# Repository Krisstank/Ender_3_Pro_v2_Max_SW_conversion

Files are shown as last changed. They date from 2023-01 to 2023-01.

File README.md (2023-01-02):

# Ender 3 Pro/V2 to Switchwire Conversion

This is a full conversion of the popular Ender 3 Pro/V2 to a Voron Switchwire and a collaborate work with [Triano](https://github.com/walttriano). The motivation came from [his awesome original conversion](https://github.com/walttriano/VoronUsers/tree/master/printer_mods/Triano/Ender_3Pro_Switchwire) that was used as a starting point, however almost everything was re-designed from scratch (in order to follow the Voron guidelines and aesthetics more accurately). Another factor that led to this re-design, was the need to be able to enclose this printer in a, visually, pleasant and, structurally, functional way. The ingenious design of 5x MGN12H Linear Rails - 300mm (dual Y axis rail) from Triano was preserved and the printing volume is ~220x220x220.

(For assembly tips regarding some unique parts of this conversion, check the [Wiki](https://github.com/boubounokefalos/Ender_SW/wiki)).

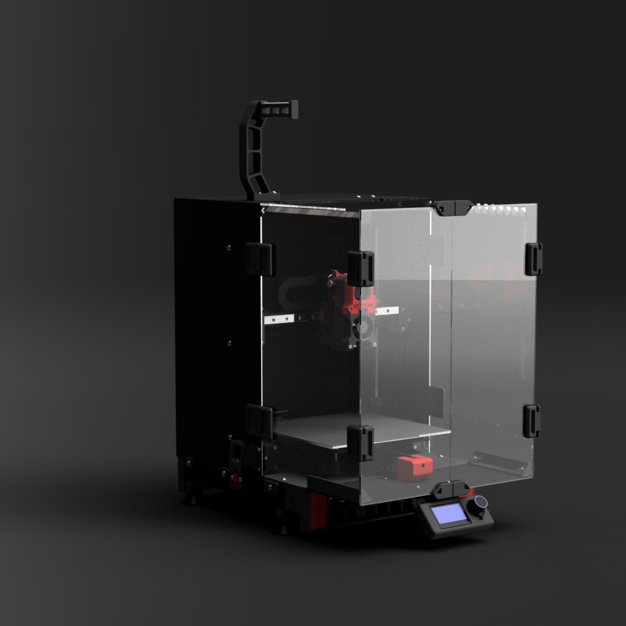
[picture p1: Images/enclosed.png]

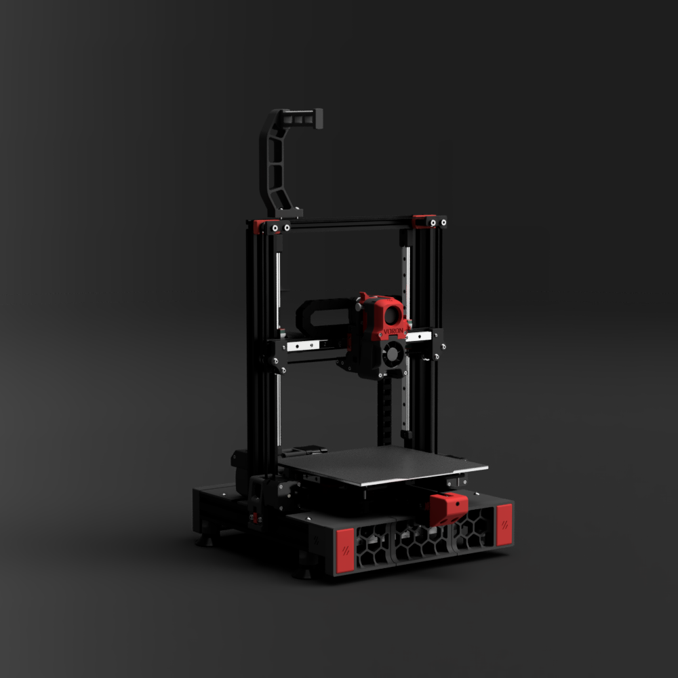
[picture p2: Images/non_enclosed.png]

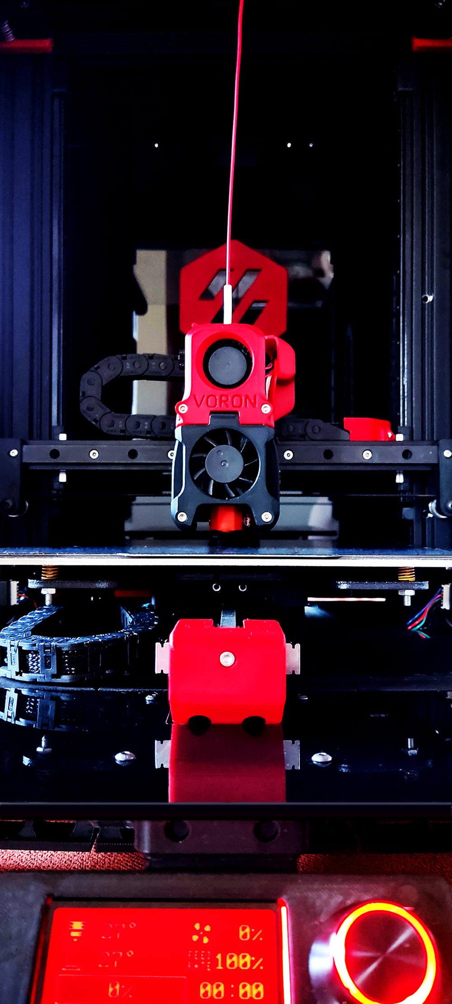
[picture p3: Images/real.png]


## Info

Various parts _can*_ be recycled from the Ender 3 Pro/V2, most important ones are:
- The frame (though a 310mm extrusion is needed for the X. You can chop the original one to length).
- The MeanWell PSU.
- The heatbed assemble.
- The original board.
- XYZ motors (as long as you can pull off the pulleys. An aftermarket 20mm motor is needed for the printhead extruder though).
- All the cables that don't go through the cable-chains (for there, silicone or PTFE cable is adviced).
- 4010 fan for the tool cooling.

*cheaping out in parts can lead into several problems, such as poor printing quality or, even worse, safety hazard. Keep that in mind and use parts from the official Switchwire BOM.

## Files

- Most of the printed part files needed for this conversion, are included in this git (you will only need to get the Afterburner print files from the [official Switchwire git](https://github.com/VoronDesign/Voron-Switchwire/tree/master/STL/Gantry/XZ_Axis/X_Carriage) ).
- CAD files (.f3d and .STEP) are provided, in order to help the building process, but they also serve as a BOM (in case you need to find proper screw lengths etc).
- DXF files in order to cut your enclosure panels.
- A printer.cfg as a starting point (based off LDO motors and SKR E3 mini V2 board).

## Credits

- Ofc to Triano for his awesome design and all the valuable help, info and support.
- To marcel#0874 for his original idea of the sticky grill endcaps.
- To sdukan#9213 for his valuable help into troubleshooting the Ender 3 V2 differences, electronics (and in general)
- To all of this awesome community of people.
- To Voron design team for all the valuable resources and the solid base.

## Disclaimer

This is a very carefuly designed build.. however mistakes could have been made so by deciding to follow this conversion, you are responsible for any possible damage done to the printer or even yourself. This is serious so keep that in mind.

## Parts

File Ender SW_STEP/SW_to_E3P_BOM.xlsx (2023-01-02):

Category | Component | Standard | Qty | Required for the Ender 3 Pro Mod?
Filament | Primary Color (Black) |  | 1 | Yes
Filament | Secondary Color (Red) |  | 1 | Yes
Printed Parts | Printed Parts |  | 1 | Yes - STLs on GitHub
Fasteners | M8x16 BHCS | ISO 7380 | 8 | M3 and M5 assorted fasteners are required. I didn't detail out the various lengths
Fasteners | M5x40 SHCS | ISO 4762 / DIN 912 | 6
Fasteners | M5x30 BHCS |  | 5
Fasteners | M5x16 BHCS | ISO 7380-1 | 12
Fasteners | M5x10 BHCS | ISO 7380-1 | 50
Fasteners | M4x8 BHCS | ISO 7380-1 | 4
Fasteners | M3x40 SHCS | ISO 4762 / DIN 912 | 7
Fasteners | M3x30 SHCS | ISO 4762 / DIN 912 | 28
Fasteners | M3x25 SHCS | ISO 4762 / DIN 912 | 2
Fasteners | M3x20 SHCS | ISO 4762 / DIN 912 | 3
Fasteners | M3x16 SHCS | ISO 4762 / DIN 912 | 12
Fasteners | M3x12 SHCS | ISO 4762 / DIN 912 | 12
Fasteners | M3x8 SHCS | ISO 4762 / DIN 912 | 66
Fasteners | M3x6 BHCS | ISO 7380-1 | 6
Fasteners | M3x6 FHCS | ISO 10642 | 16
Fasteners | M3x12 FHCS | ISO 10642 | 9
Fasteners | 6x6x3 Spacer
Fasteners | M2x10 Self Tapping Screw for Plastics |  | 8
Fasteners | M3 Threaded Insert |  | 54
Fasteners | 5x10x1 Shim Ring | DIN 988 | 19
Fasteners | M3 Hexnut | ISO 4033 / DIN 934 | 3
Fasteners | M3 T-nut (For 2020 extrusions) |  | 13
Fasteners | M3 T-nut (For 3030 extrusions) |  | 12
Fasteners | M5 T-nut (For 2020 extrusions) |  | 12
Fasteners | M5 T-nut (For 3030 extrusions) |  | 52
Motion | GT2 Open Belt LL-2GT-6 (6mm wide) - 1500mm |  | 2 | Yes
Motion | GT2 Open Belt LL-2GT-6 (6mm wide) - 800mm |  | 1 | Yes
Motion | GT2 20T (6mm wide) Pulley (5mm bore) |  | 3 | Yes
Motion | F695 2RS Bearing |  | 20 | Yes
Motion | Linear Rail MGN12H (300mm) |  | 4 | 5 (1 additional)
Motion | Key-bak Super48 13oz |  | 1 | Yes
Vibration Management | Rubber Compressor Foot |  | 4 | No - printed with the forward and aft grills
Electronics | Omron Mouse Button - Micro Switch |  | 2 | 1 - the Y axis microswitch is reused
Electronics | Omron TL-Q5MC2 - NPN, NC, 5mm Sense |  | 1 | Yes
Electronics | BAT85 Diode |  | 1 | Yes
Electronics | NEMA17 Motor 17HS15-1504S1 |  | 3 | New or Reused. If you have a gear puller, you can reuse these. I bought new ones. You also need the smaller motor for the afterburner.
Electronics | Mean Well LRS-350-24 PSU |  | 1 | Reused
Electronics | Mean Well RS-25-5 PSU |  | 1 | Yes
Electronics | ZF - Rocker Switches DPST 16A ON-OFF |  | 1 | No
Electronics | Fuse Medium Time Delay Acting 8A 250V Holder Cartridge 5 X 20mm Glass |  | 2 | Yes
Electronics | TycoElectronics - 10EGG1-2 (Normal) or 10EHG1-2 (Medical): Filtered Power Inlet |  | 1 | No
Electronics | IEC320 C14 Inlet - Push-fit - w/ Rocker Switch & Fuse |  | 1 | Yes
Electronics | 40x40x10 Axial Fan- Ball Bearing (24V) |  | 1 | Yes
Electronics | 40x40x20 Centrifugal Blower Fan - Ball Bearing (24V) |  | 1 | Yes
Electronics | 60x60x20 Axial Fan (24V) |  | 1 | Yes
Controller | RaspberryPi4 |  | 1 | Reused ( I was running Octoprint)
Controller | MicroSD Card |  | 1 | Reused
Controller | USB C Power Cable |  | 1 | Reused
Controller | SKR Mini E3 V2 |  | 1 | Reused or new. I had upgraded before the mod
Controller | USB Cable A-male Mini B-male (Included with SKR Mini) |  | 1 | A right angle USB mini is required
Controller | Mini 12864 Display (Type B) |  | 1 | Optional. I don't use one
Frame | Misumi 3060 x 520mm - HFSB6-3060-520-AH105-BH415-AV180 |  | 2 | Use Ender 3 Pro frame
Frame | Misumi 3030 x 400mm - HFSB6-3030-400-TPW |  | 2 | Use Ender 3 Pro frame
Frame | Misumi 3030 x 360mm - HFSB6-3030-360-LCH-RCH |  | 1 | Use Ender 3 Pro frame
Frame | Misumi 3030 x 300mm - HFSB6-3030-300-TPW |  | 2 | Use Ender 3 Pro frame
Frame | Misumi 2020 x 340mm - HFSB5-2020-340-AH15-BH325 |  | 1 | Use Ender 3 Pro frame
Frame | Misumi 2020 x 340mm - HFSB5-2020-340 |  | 1 | Use Ender 3 Pro frame
Misc | Bowden Tube (4mm OD, 3mm ID) |  | 3m | Reused
Misc | 6mm x 3mm Round Neodymium Magnets |  | 8 | No
Cables | Fork Spade Terminal |  | 15 | I have a various assorment of connectors as Voron recommends. The quantities may be off and everyone has their own preferences for wiring Yes
Cables | Insulated Crimp Receptical |  | 10 | Yes
Cables | Nylon Cable Ties 4" |  | 100 | Yes
Cables | MicroFit3 Male Pin (43031-0007) |  | 40 | Yes
Cables | MicroFit3 Female Pin (43030-0007) |  | 40 | Yes
Cables | MicroFit Connector Receptacle 4 Position (43645-0400) |  | 4 | Yes
Cables | MicroFit Connector Receptacle 3 Position (43645-0300) |  | 1 | Yes
Cables | MicroFit Connector Receptacle 2 Position (43645-0200) |  | 6 | Yes
Cables | MicroFit Connector Plug 4 Position (43640-0401) |  | 4 | Yes
Cables | MicroFit Connector Plug 3 Position (43640-0301) |  | 1 | Yes
Cables | MicroFit Connector Plug 2 Position (43640-0201) |  | 6 | Yes
Cables | JST-XH Female Pin |  | 40 | Yes
Cables | JST-XH Connector Plug 4 Position |  | 4 | Yes
Cables | JST-XH Connector Plug 3 Position |  | 4 | Yes
Cables | JST-XH Connector Plug 2 Position |  | 4 | Yes
Cables | 24AWG Silicone Cable (100ft total) |  | 1 | Yes
Cables | 16AWG Silicone Cable (10ft total) |  | 1 | Yes
Cables | 20AWG Silicone Cable (10ft total) |  | 1 | Yes
Cables | 10x11 Cable Chain - Openable (1m) |  | 2 | Yes
Panels | Opaque Enclosure Panels |  | 6 | No (https://www.michaels.com/corrugated-board-by-creatology/M10567770.html)
Panels | Side/Front/Top Acrylic Panels |  | 5 | No (https://www.tapplastics.com/product/plastics/cut_to_size_plastic/acrylic_sheets_clear/508)
Buildplate | Prusa MK52 Heated Bed - 24V |  | 1 | Reused Ender 3 bed
Buildplate | Spring Steel Sheet for Prusa MK52 Bed (included with TL Heated Bed) |  | 1
Buildplate | Prusa MK3 Y Carrier |  | 1
Afterburner |  |  |  | The Afterburner is unchanged. Check the BOM and sourcing guide

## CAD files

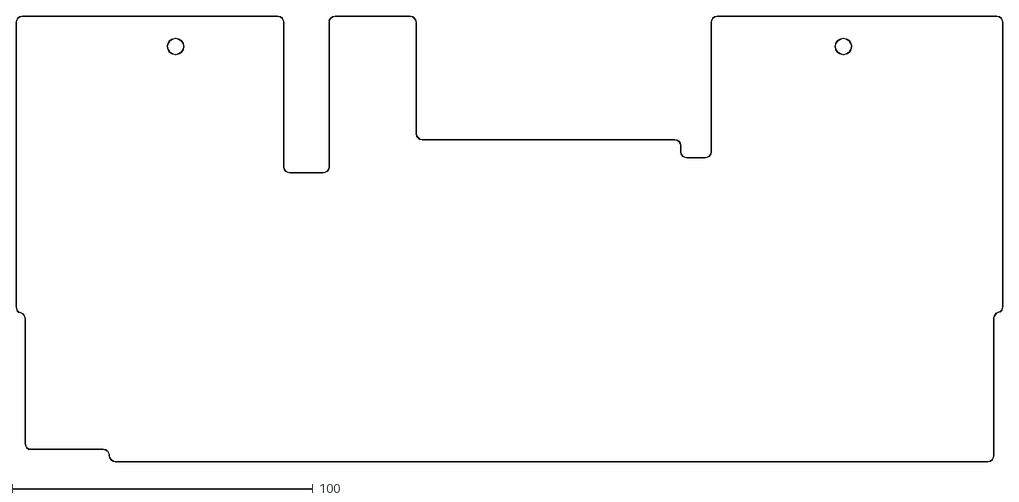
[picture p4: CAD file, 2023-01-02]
DXF/BLACK/deck_left.dxf
328.0 x 148.0

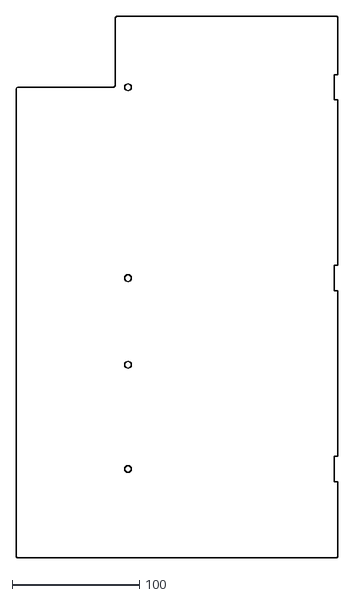
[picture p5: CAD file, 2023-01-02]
DXF/BLACK/M4_compatible/rear_side_panel_x2_M4_compatible.dxf
253.0 x 426.0

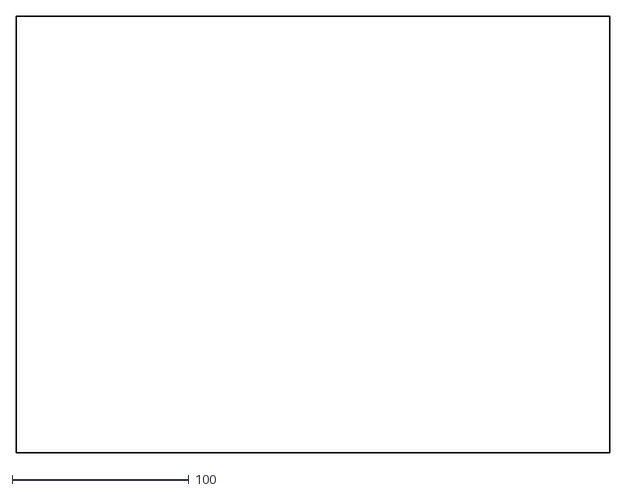
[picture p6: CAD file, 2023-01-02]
DXF/CLEAR/front_top_clear.dxf
336.0 x 247.0

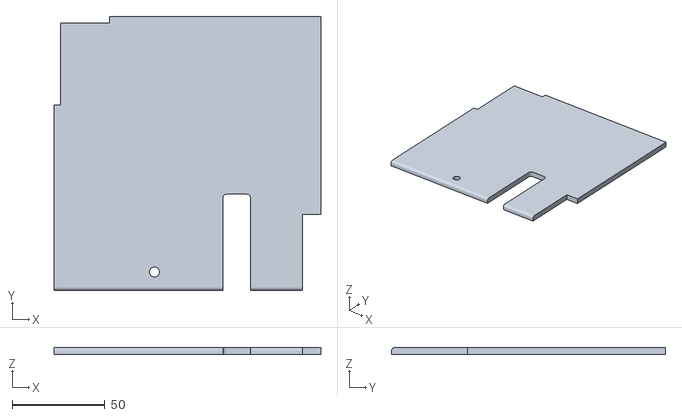
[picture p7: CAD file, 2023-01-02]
STL/Decks/rear_left.stl
144.0 x 148.0 x 4.00

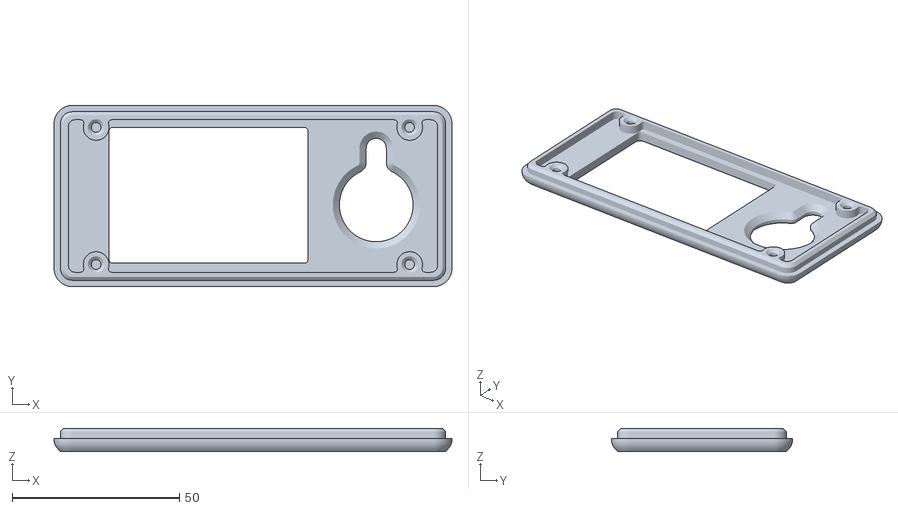
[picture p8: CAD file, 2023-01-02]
STL/Electronics/LCD/Mini12864/lcd_case_front_mini12864.stl
119.0 x 54.2 x 7.00

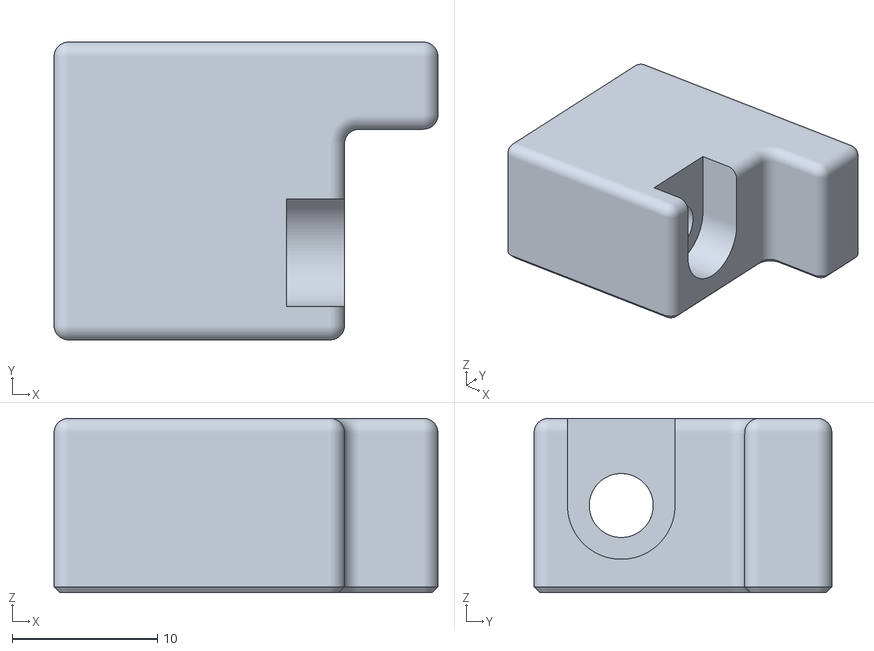
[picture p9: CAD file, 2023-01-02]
STL/Electronics/PS_4040_slide_mount_x2.stl
26.4 x 20.5 x 12.0

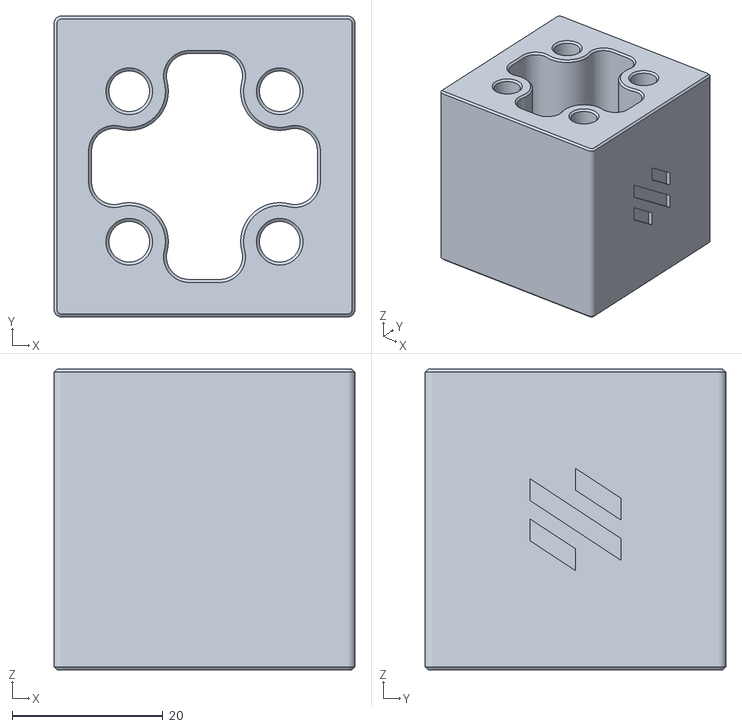
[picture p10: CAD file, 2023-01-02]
STL/frame_extension_x2.stl
40.0 x 40.0 x 40.0

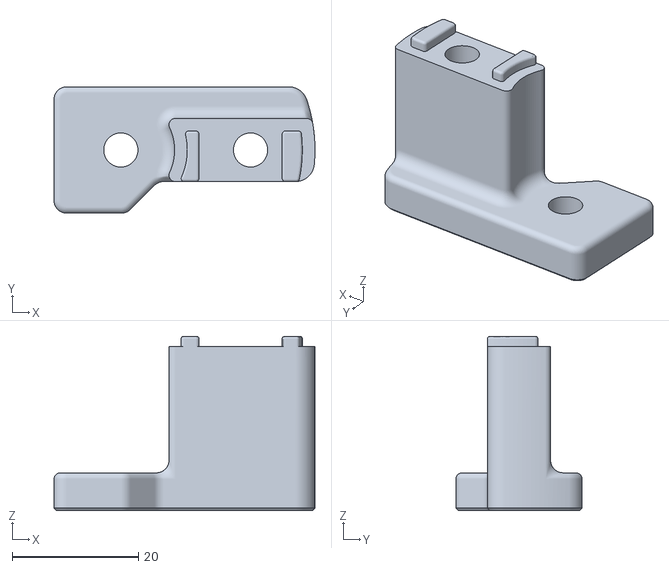
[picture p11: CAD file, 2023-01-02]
STL/Gantry/XZ_Axis/upper_idler_support_a_right.stl
41.3 x 20.0 x 27.6

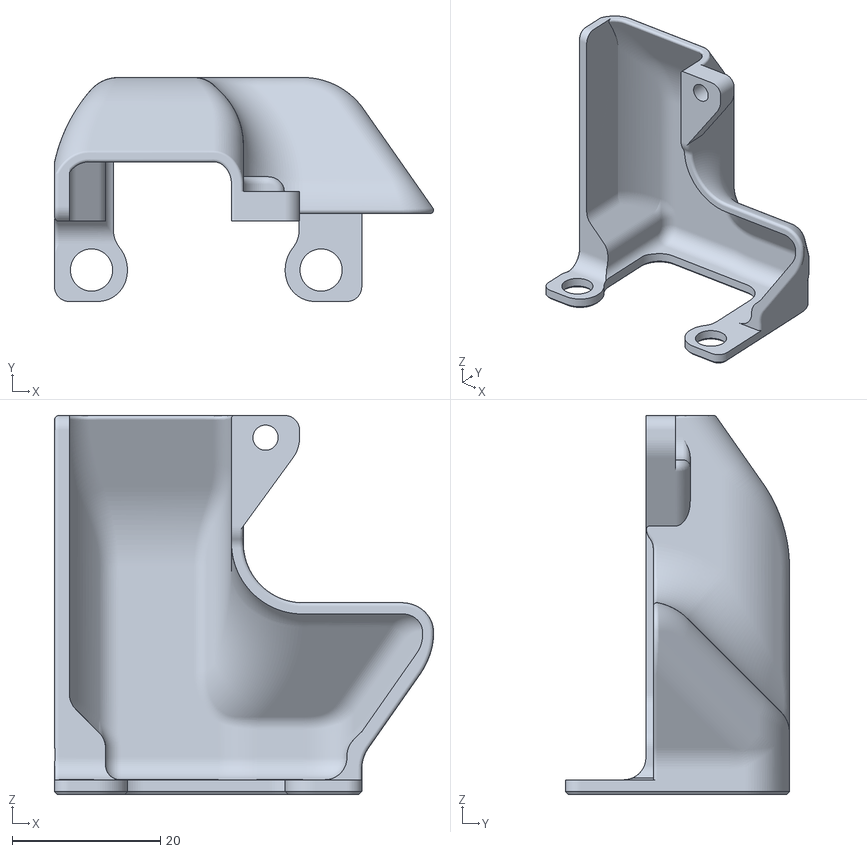
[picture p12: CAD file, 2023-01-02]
STL/Gantry/XZ_Axis/X_Axis/[a]_connector_cover.stl
51.2 x 30.3 x 51.2

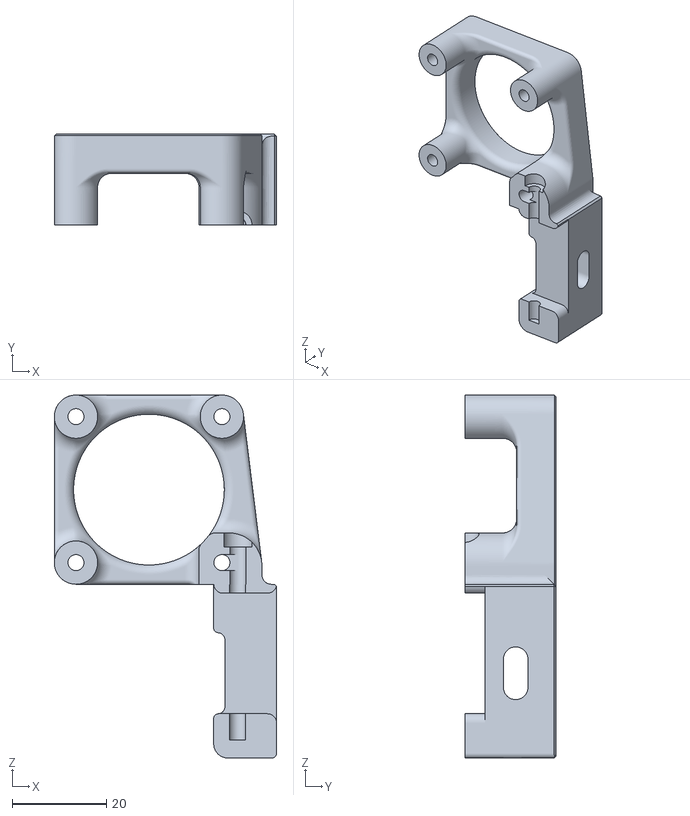
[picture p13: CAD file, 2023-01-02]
STL/Gantry/XZ_Axis/XZ_Axis_Max/x_motor_mount_b_max.stl
47.2 x 19.4 x 77.1

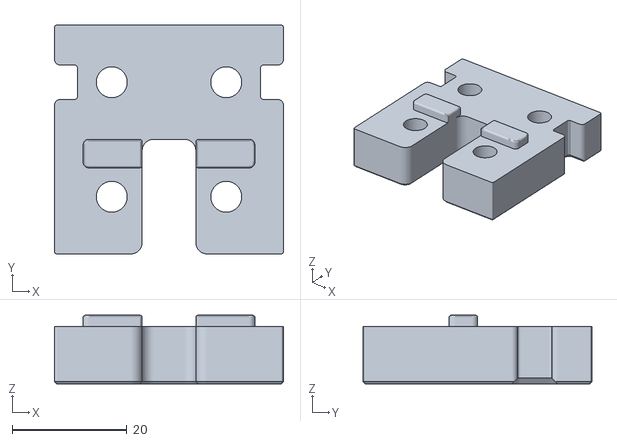
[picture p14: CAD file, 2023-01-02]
STL/Gantry/Y_Axis/y_motor_mount_bracket_enderV2.stl
40.0 x 40.0 x 12.0

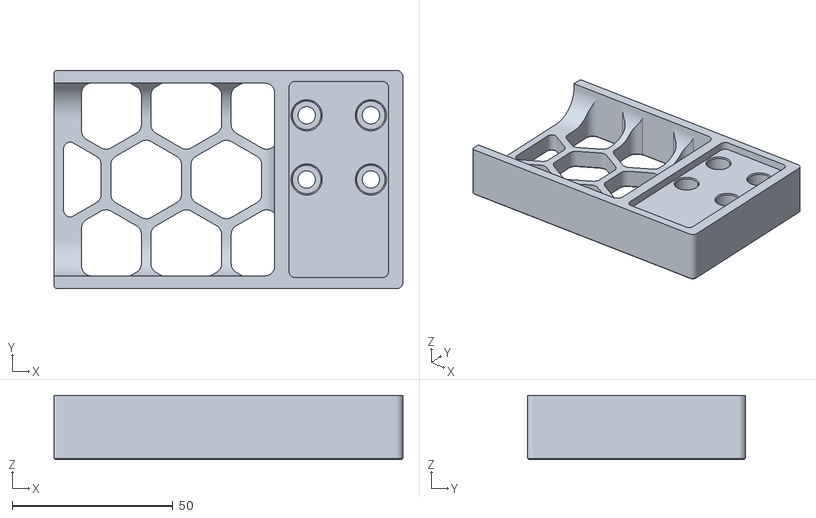
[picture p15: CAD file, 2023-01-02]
STL/Grills/grill_front_right.stl
108.7 x 68.0 x 20.0

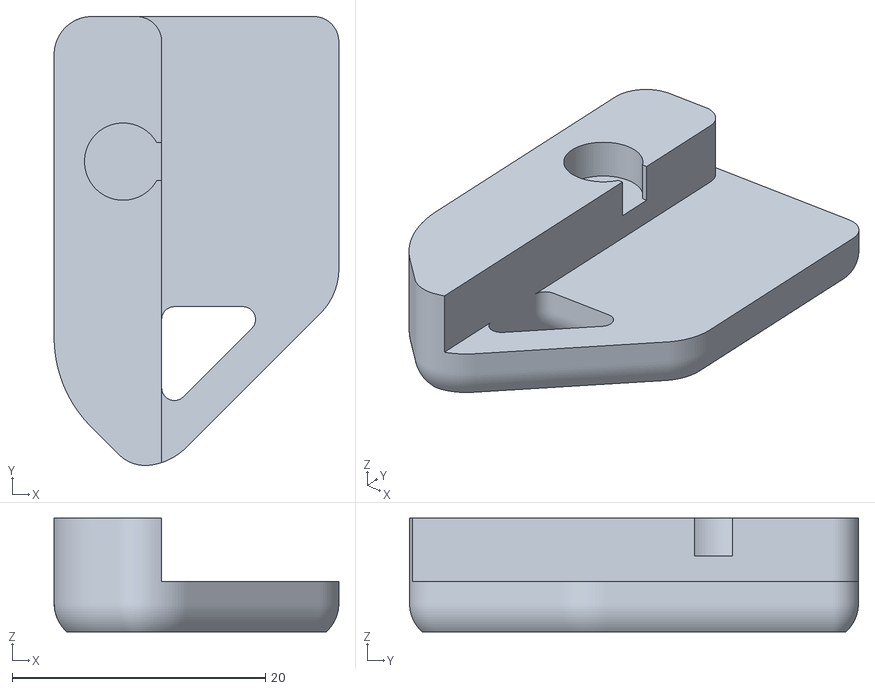
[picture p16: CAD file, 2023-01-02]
STL/Panel_Mounting/Doors/door_handle_b_x2.stl
22.5 x 35.5 x 9.00

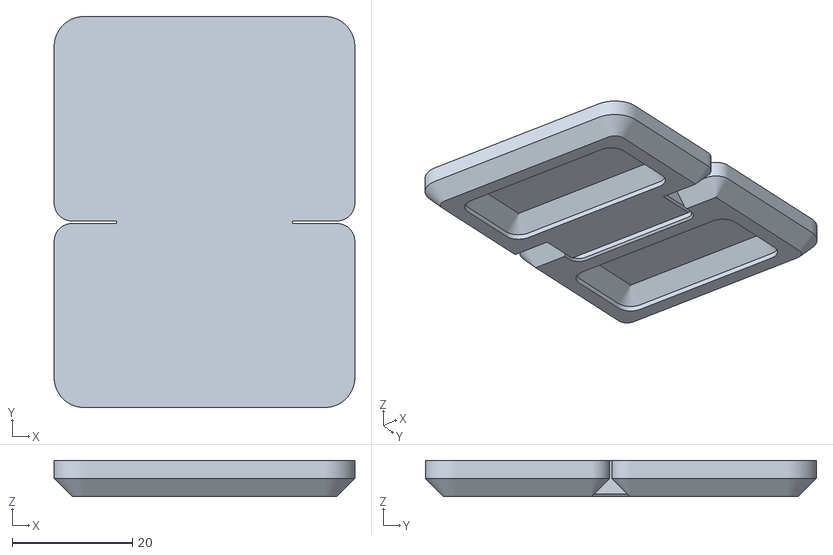
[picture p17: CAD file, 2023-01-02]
STL/Panel_Mounting/side_strap_x4.stl
50.0 x 65.0 x 6.00

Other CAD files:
DXF/BLACK/top_rear_panel.dxf
DXF/CLEAR/front_side_clear_x2.dxf
STL/Decks/rear_right.stl
STL/Electronics/LCD/Mini12864/mount_mini12864.stl
DXF/BLACK/deck_right.dxf
DXF/BLACK/front_bottom_panel.dxf
DXF/BLACK/rear_panel.dxf
DXF/BLACK/rear_side_panel_x2.dxf
DXF/CLEAR/front_clear_door_x2.dxf
STL/Decks/front_left.stl
STL/Decks/front_right.stl
STL/Electronics/LCD/Mini12864/lcd_case_rear_mini12864.stl
STL/Electronics/PS_4040_mount_a.stl
STL/Electronics/PS_4040_mount_b.stl
STL/Electronics/rpi3_mount.stl
STL/Electronics/rpi3_shelf.stl
STL/Electronics/rs_25_mount.stl
STL/Electronics/skr_mini_e3_mount.stl
STL/Gantry/XZ_Axis/XZ_Axis_Max/x_motor_mount_a_max.stl
STL/Gantry/XZ_Axis/XZ_Axis_Max/z_motor_mount_a_max.stl
STL/Gantry/XZ_Axis/XZ_Axis_Max/z_motor_mount_b_max.stl
STL/Gantry/XZ_Axis/[a]_upper_idler_support_b_left.3mf
STL/Gantry/XZ_Axis/[a]_upper_idler_support_b_left.stl
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

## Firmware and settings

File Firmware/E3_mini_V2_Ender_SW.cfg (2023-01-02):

#This is an example configuration file, for the Ender Switchwire Conversion with the SKR E3 mini V2.

[virtual_sdcard]
path: ~/gcode_files

[stepper_x]
step_pin: PB13
dir_pin: PB12
enable_pin: !PB14
rotation_distance: 40
microsteps: 16
endstop_pin: ^PC0
position_endstop: 220
position_min: 0
position_max: 220
homing_speed: 40
homing_positive_dir: true

[tmc2209 stepper_x]
uart_pin: PC11
tx_pin: PC10
uart_address: 0
run_current: 0.5
hold_current: 0.3
interpolate: True
stealthchop_threshold: 250

[stepper_y]
step_pin: PB10
dir_pin: PB2
enable_pin: !PB11
rotation_distance: 40
microsteps: 16
endstop_pin: ^PC1
position_endstop: 0
position_min: 0
position_max: 220
homing_speed: 40
homing_positive_dir: false

[tmc2209 stepper_y]
uart_pin: PC11
tx_pin: PC10
uart_address: 2
run_current: 0.5
hold_current: 0.3
interpolate: True
stealthchop_threshold: 250

[stepper_z]
step_pin: PB0
dir_pin: PC5
enable_pin: !PB1
microsteps: 16
rotation_distance: 40
endstop_pin: probe:z_virtual_endstop
position_max: 220
homing_speed: 40
position_min: -3.0

[tmc2209 stepper_z]
uart_pin: PC11
tx_pin: PC10
uart_address: 1
run_current: 0.5
hold_current: 0.3
interpolate: True
stealthchop_threshold: 250

[homing_override]
axes: z
set_position_z: 0
gcode:
    G90
    G0 Z5 F500
    G28 X0 Y0
    G0 X110 Y110 F9000
    G28 Z0
    G0 Z5 F500

[bed_mesh]
speed: 40
horizontal_move_z: 6
mesh_min: 25,35.0
mesh_max: 220.0,220
probe_count: 6,6
algorithm: bicubic
fade_start: 1
fade_end: 10
fade_target: 0

[probe]
pin: ^PC2
x_offset: 0.0
y_offset: 25.0
speed: 40

[extruder]
max_extrude_only_distance: 100.0
step_pin: PB3
dir_pin: PB4
enable_pin: !PD2
microsteps: 32
rotation_distance: 6.906
nozzle_diameter: 0.400
filament_diameter: 1.750
heater_pin: PC8
pressure_advance: 0.074
pressure_advance_smooth_time: 0.040
sensor_type: ATC Semitec 104GT-2
sensor_pin: PA0
control = pid
pid_Kp: 21.527
pid_Ki: 1.063
pid_Kd: 108.982
min_temp: 0
max_temp: 270

[tmc2209 extruder]
uart_pin: PC11
tx_pin: PC10
uart_address: 3
run_current: 0.5
hold_current: 0.3
interpolate: True

[gcode_macro PRINT_START]
#   Use PRINT_START for the slicer starting script - please customise for your slicer of choice
# Start GCODE should be for Prusa Slicer or SuperSlicer: print_start EXTRUDER_TEMP=[first_layer_temperature] BED_TEMP=[first_layer_bed_temperature]
# Start GCODE should be for Cura: print_start EXTRUDER_TEMP=[material_print_temperature] BED_TEMP=[material_bed_temperature]
gcode:
    M117 Homing...
    G28 Y0 X0 Z0
    #BED_MESH_PROFILE LOAD=default
    
    G91 ; relative movements
    G1 Z10 F5000 ; lift nozzle
    G90 ; back to absolute
    G0 X10 Y10 F6000

    M117 Heating...
    M140 S{BED_TEMP}                    ; set bed final temp
    M104 S{EXTRUDER_TEMP}               ; set extruder final temp
    M190 S{BED_TEMP}                    ; wait for bed final temp
    M109 S{EXTRUDER_TEMP}               ; wait for extruder final temp
    
    M117 Home Z with hot bed
    G28 Z0
    BED_MESH_CALIBRATE

    PURGE
    PRIME_LINE

    G90
    G1 Z5.0 F6000 
    G92 E0                              ;zero the extruded length again
    G1 F9000
    M117 Printing

[gcode_macro PURGE]
gcode:
    SAVE_GCODE_STATE NAME=BEFORE_PURGE
    M117 Purging
    G0 X0 Y0 F5000
    G91
    G1 E9 F1000
    G90
    RESTORE_GCODE_STATE NAME=BEFORE_PURGE

[gcode_macro PRIME_LINE]
gcode:
    SAVE_GCODE_STATE NAME=BEFORE_PRIME
    M117 Prime Line
    G0 X10.0 Y3.0 F5000.0  ; Go to X3 Y3
    G1 Z0.2 F200            ; Set nozzle height
    G92 E0.0                ; reset extrusion distance
    G1 X60.0 E9.0 F1000.0   ; intro line
    G1 X100.0 E10 F1000.0   ; intro line
    G92 E0.0                ; reset extrusion distance
    G1 Z1 F5000             ; Lift Z
    RESTORE_GCODE_STATE NAME=BEFORE_PRIME  

[gcode_macro PRINT_END]
#   Use PRINT_END for the slicer ending script - please customise for your slicer of choice
gcode:

    M400                           ; wait for buffer to clear
    G92 E0                         ; zero the extruder
    G1 E-1.0 F3600                 ; retract filament
    G91                            ; relative positioning
    G0 Z1.00 X20.0 Y20.0 F2000     ; move nozzle to remove stringing
    TURN_OFF_HEATERS
    M107                           ; turn off fan
    G1 Z5 F3000                    ; move nozzle up 5mm
    G90                            ; absolute positioning
    G0 X0 Y220 F3600               ; park nozzle at rear
    BED_MESH_CLEAR
    M117 Finished!                 ; display message

[controller_fan my_controller_fan]
pin: PA1
max_power: 1.00
kick_start_time: 0.200
heater: heater_bed

[heater_bed]
heater_pin: PC9
sensor_type: EPCOS 100K B57560G104F
sensor_pin: PC3
control = pid
pid_Kp: 54.027
pid_Ki: 0.770
pid_Kd: 948.182
min_temp: 0
max_temp: 130

[fan]
pin: PC6

# thermally controlled hotend fan
[heater_fan my_nozzle_fan]
pin: PC7
max_power: 1.0
kick_start_time: 0.100
heater: extruder
heater_temp: 70.0
fan_speed: 0.5

[mcu]
serial: /dev/serial/by-id/usb-Klipper_stm32f103xe_30FFD7054250323638802457-if00

[printer]
kinematics: corexz
max_velocity: 200
max_accel: 2000
max_accel_to_decel: 1000
max_z_velocity: 50
max_z_accel: 1000
square_corner_velocity: 4.0

[static_digital_output usb_pullup_enable]
pins: !PA14

[output_pin LIGHTS]
pin: PC12
value: 0
shutdown_value: 0

[display_status]

[display]
#    FYSETC mini12864 LCD Display v2.1
lcd_type: uc1701
cs_pin: PB8
a0_pin: PB15
rst_pin: PB9
encoder_pins: ^PA9,^PA10
click_pin: ^!PB5
contrast: 63
spi_software_sclk_pin: PA5
spi_software_mosi_pin: PA7
spi_software_miso_pin: PA6

[neopixel fysetc_mini12864]
#    To control Neopixel RGB in mini12864 display
pin: PA15
chain_count: 3
initial_RED: 0.2
initial_GREEN: 0.5
initial_BLUE: 1.0
color_order: RGB

#[moonraker]
#trusted_clients:
#    192.168.1.0/24

[gcode_macro lights_on]
gcode:
    SET_PIN PIN=LIGHTS VALUE=1.0

[gcode_macro lights_off]
gcode:
    SET_PIN PIN=LIGHTS VALUE=0.0

[pause_resume]

[gcode_macro CANCEL_PRINT]
rename_existing: BASE_CANCEL_PRINT
default_parameter_X: 220
default_parameter_Y: 220
default_parameter_Z: 10
gcode:
    M104 S0
    M140 S0
    M141 S0
    M106 S0
    CLEAR_PAUSE
    RESET_SD
    BASE_CANCEL_PRINT

[gcode_macro PAUSE]
rename_existing: BASE_PAUSE
default_parameter_X: 220
default_parameter_Y: 220
default_parameter_Z: 10
gcode:
    SAVE_GCODE_STATE NAME=PAUSE_state
    BASE_PAUSE
    G91
    G1 E-1.7 F2100
    G1 Z{Z}
    G90
    G1 X{X} Y{Y} F6000
    G91

[gcode_macro RESUME]
rename_existing: BASE_RESUME
gcode:
    G91
    G1 E1.7 F2100
    G91
    RESTORE_GCODE_STATE NAME=PAUSE_state MOVE=1
    BASE_RESUME

[gcode_macro DISABLE_MOTORS]
gcode:
    M18

[gcode_macro ZUP]
gcode:
    SET_GCODE_OFFSET Z_ADJUST=0.01 MOVE=1

[gcode_macro ZDOWN]
gcode:
    SET_GCODE_OFFSET Z_ADJUST=-0.01 MOVE=1
